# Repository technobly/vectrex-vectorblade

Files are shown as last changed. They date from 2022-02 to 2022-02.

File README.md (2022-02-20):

Vectrex Vectorblade PCB by Brett Walach
===

[Malban's Vectorblade PCB design](http://vide.malban.de/vectorblade/building-vectorblade/vectorblade-build-the-hardware), optimized with single gate SMT IC's (AND & NOT), 8 color RGB LED, and some gorgeous artwork applied.  Looks great in black soldermask with ENIG (gold flash) finish!

Yes these fit in [Sean Kelly reproduction cartridge shells](http://www.vectrexmulti.com/order2.html#!/Vectrex-Empty-Cartridge-Shells/c/38886086/offset=0&sort=normal) perfectly!

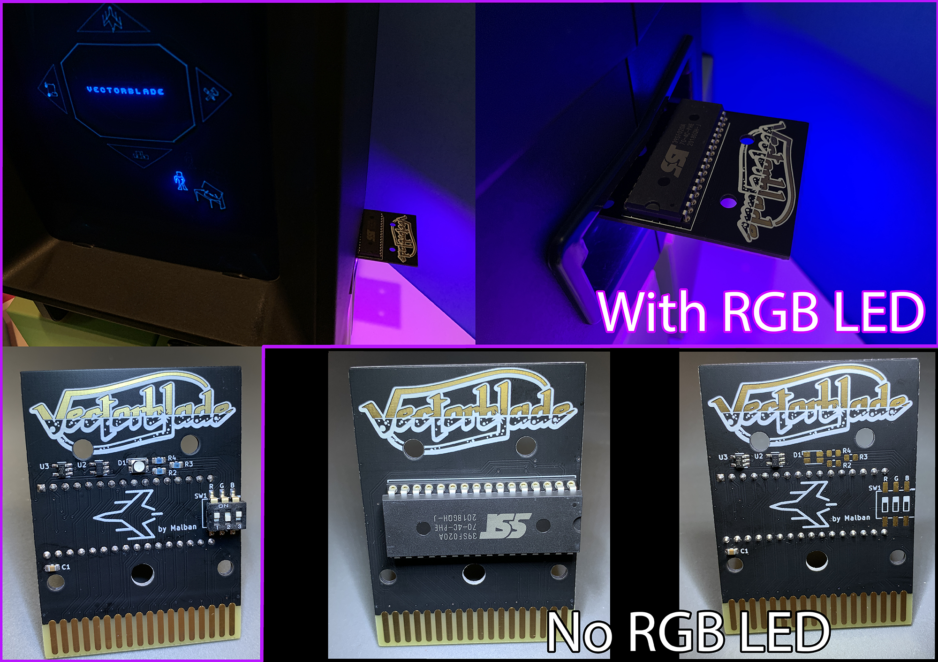
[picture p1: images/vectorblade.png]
VB


BOM and Parts ordering
===

All the parts are described in [Bill of Materials](bom/)

You can use this Digi-Key shared cart to order the parts!
[Vectrex Vectorblade](https://www.digikey.com/short/90np89zn)

Ordering PCB's
===

OSHPark is a good place to order with purple or the new "after dark" theme color scheme.  You can upload the KiCad `vextrex-vectorblade.kicad_pcb` there directly.  I would download this entire Github repo ZIP file first though instead of just trying to save the PCB file from your browser.

Another way to order PCB's is by using the included [gerbers](gerbers/vectrex-vectorblade-v1.0.zip) and uploading those with all of the necessary specs to companies like [PCBWay](https://www.pcbway.com) or [JLCPCB](https://jlcpcb.com)

Don't forget to make your board finish at least ENIG (gold flash) with a 45 degree chamfered edge.

LICENSE
===

CERN OHL v2.0 Permissive - essentially do whatever you want, but if you make a ton of money off of this... [buy me a coffee please!](https://buymeacoffee.com/walach)  Full [LICENSE here](LICENSE)

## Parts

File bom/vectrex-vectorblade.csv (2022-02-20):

Date: | Sunday, October 04, 2020 at 12:01:03 PM
Tool: | Eeschema (5.1.6-87-g1447494bc)
Generator: | /private/var/folders/z4/810dpjjx40sdk49yrs8fc2m80000gn/T/AppTranslocation/1DF89409-4AD7-4826-80D4-C05ED8546A72/d/kicad.app/Contents/SharedSupport/plugins/bom_csv_grouped_by_value_with_fp.py
Component Count: | 10
Ref | Qnty | Value | Cmp name | Footprint | Description | Vendor
C1, | 1 | 0.1uF 0805 | C | Capacitor_SMD:C_0805_2012Metric_Pad1.15x1.40mm_HandSolder | Unpolarized capacitor
D1, | 1 | ASMB-MTB0-0A3A2 | ASMB-MTB0-0A3A2 | vectrex-vectorblade:LED_Avago_PLCC4_3.2x2.8mm_CW | Tricolor Black Surface LED, Common Anode Pin 1, PLCC-4
R2, R3, | 2 | 150 0805 | R | Resistor_SMD:R_0805_2012Metric_Pad1.15x1.40mm_HandSolder | Resistor
R4, | 1 | 200 0805 | R | Resistor_SMD:R_0805_2012Metric_Pad1.15x1.40mm_HandSolder | Resistor
SW1, | 1 | SW_DIP_x03 | SW_DIP_x03 | Button_Switch_SMD:SW_DIP_SPSTx03_Slide_6.7x9.18mm_W8.61mm_P2.54mm_LowProfile | 3x DIP Switch, Single Pole Single Throw (SPST) switch, small symbol
U1, | 1 | SST39SF020 | SST39SF020 | Package_DIP:DIP-32_W15.24mm_Socket | Silicon Storage Technology (SSF) 256k x 8 Flash ROM
U1, | 1 | 115-87-632-41-003101 | 115-87-632-41-003101 | Package_DIP:DIP-32_W15.24mm_Socket | CONN IC DIP SOCKET 32POS GOLD
U2, | 1 | NC7ST08M5X (do not substitute) | NC7ST08M5X (do not substitute) | Package_TO_SOT_SMD:SOT-23-5_HandSoldering | Single AND Gate, Low-Voltage CMOS
U3, | 1 | SN74AHC1G04DBVR (Schmitt-Trigger) | 74AHC1G04 | Package_TO_SOT_SMD:SOT-23-5_HandSoldering | Single NOT Gate, Low-Voltage CMOS

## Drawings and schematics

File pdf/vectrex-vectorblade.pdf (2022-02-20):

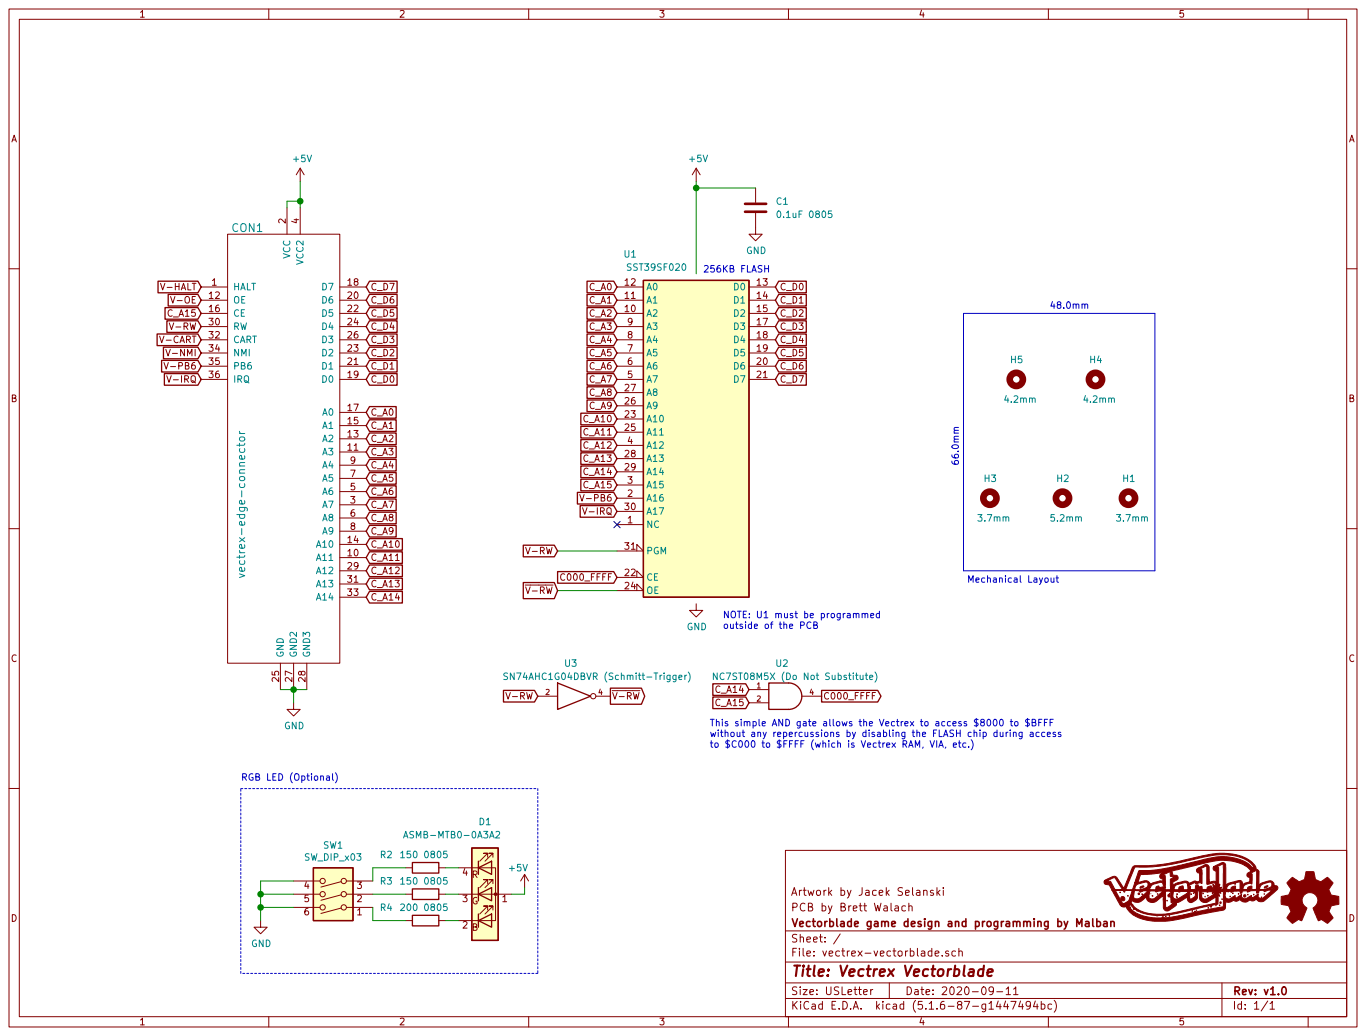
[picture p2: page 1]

4 A6 5 A8 6 A5 7 A9 8 A4 9 A11 10 D6 20 RW 30 A3 11 D1 21 A13 31 OE 12 D5 22 CART 32 A2 13 D2 23 A14 33 A10 14 D4 24 NMI 34 A1 15 GND 25 PB6 35 CE 16 D3 26

NOTE: U1 must be programmed outside of the PCB

This simple AND gate allows the Vectrex to access $8000 to $BFFF
without any repercussions by disabling the FLASH chip during access
to $C000 to $FFFF (which is Vectrex RAM, VIA, etc.)

Artwork by Jacek Selanski
PCB by Brett Walach
File: vectrex-vectorblade.sch Sheet: / Vectorblade game design and programming by Malban

Id: 1/1 Title: Vectrex Vectorblade

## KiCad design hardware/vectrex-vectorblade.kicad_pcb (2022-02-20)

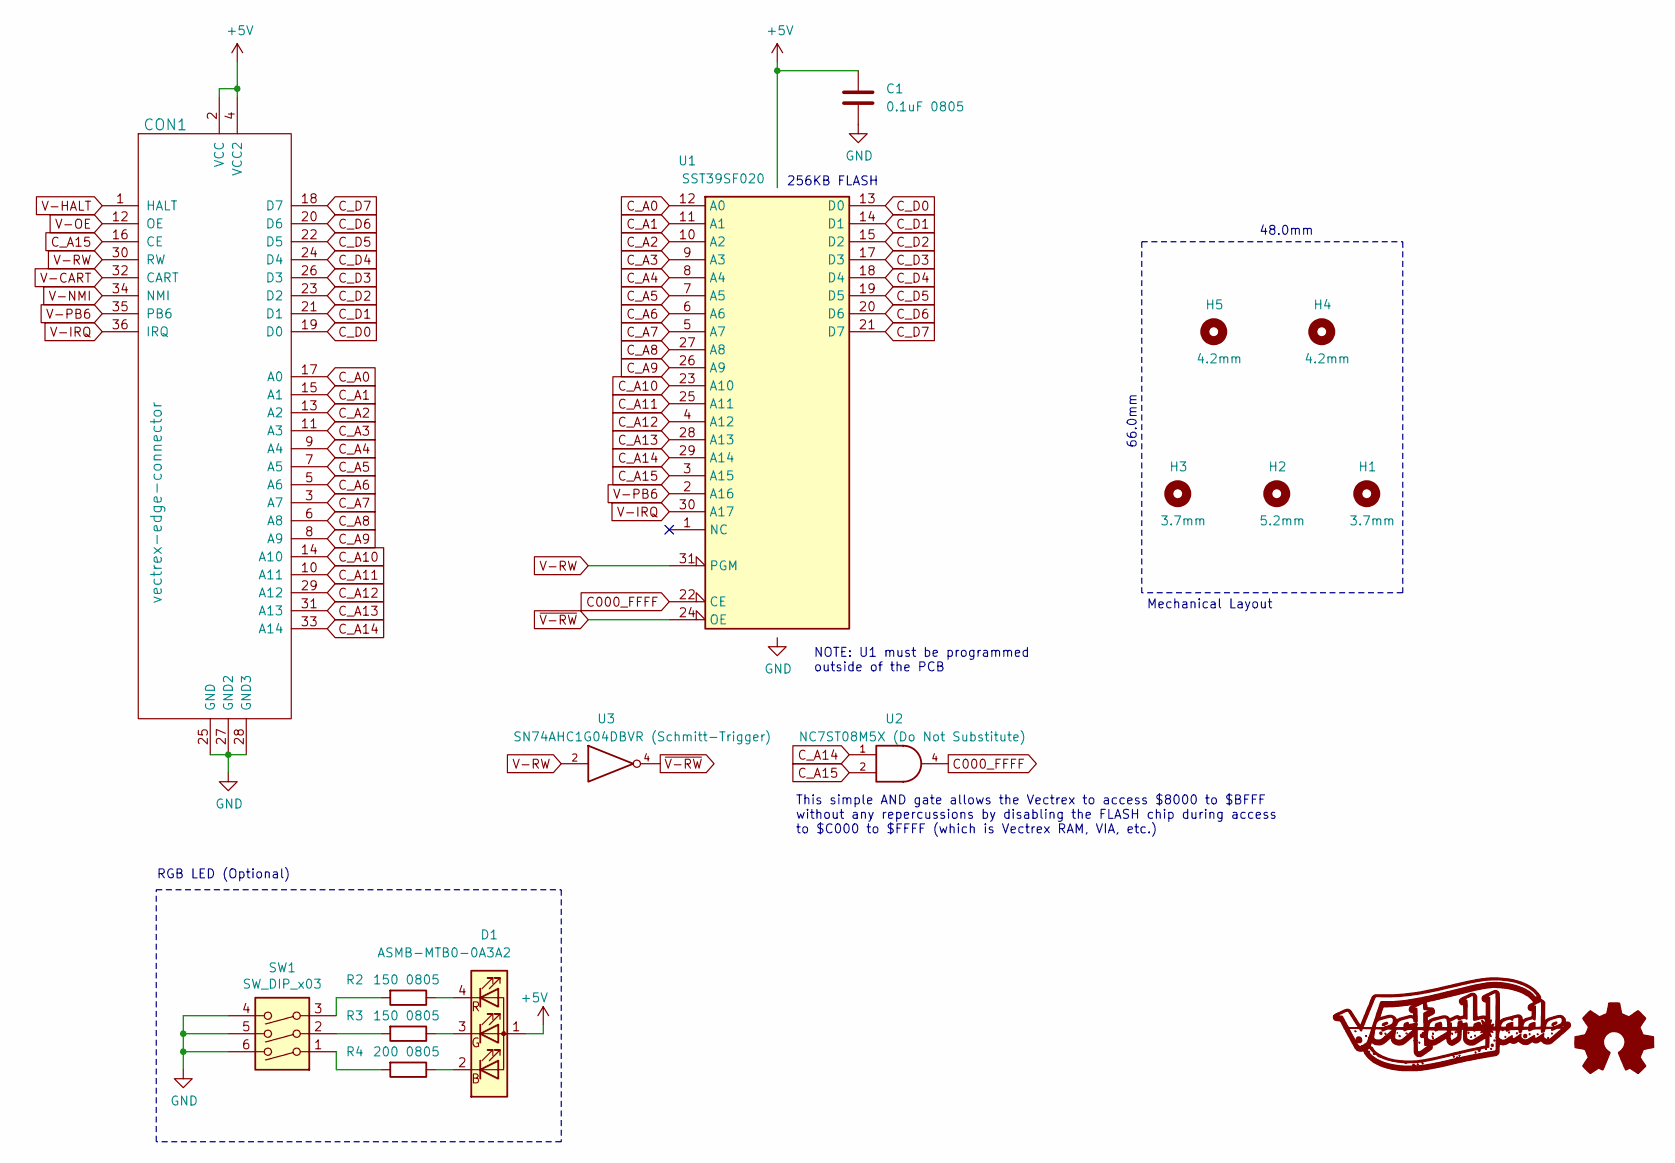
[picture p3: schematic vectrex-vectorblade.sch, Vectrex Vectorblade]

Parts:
C1: 0.1uF 0805; C_0805_2012Metric_Pad1.15x1.40mm_HandSolder
CON1: vectrex-edge-connector; vectrex-edge-connector-thinner-no-soldermask
D1: ASMB-MTB0-0A3A2; LED_Avago_PLCC4_3.2x2.8mm_CW
H1, H3: 3.7mm; Mounting_Hole_D3.7mm
H2: 5.2mm; Mounting_Hole_D5.2mm
H4, H5: 4.2mm; Mounting_Hole_D4.2mm
R2, R3: 150 0805; R_0805_2012Metric_Pad1.15x1.40mm_HandSolder
R4: 200 0805; R_0805_2012Metric_Pad1.15x1.40mm_HandSolder
SW1: SW_DIP_x03; SW_DIP_SPSTx03_Slide_6.7x9.18mm_W8.61mm_P2.54mm_LowProfile
U1: SST39SF020; DIP-32_W15.24mm_Socket
U2: NC7ST08M5X (Do Not Substitute); SOT-23-5_HandSoldering
U3: SN74AHC1G04DBVR (Schmitt-Trigger); SOT-23-5_HandSoldering

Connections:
+5V: C1.1, CON1.2 (VCC), CON1.4 (VCC2), D1.1 (A), U1.32 (VCC), U2.5 (VCC), U3.5 (VCC)
C000_FFFF: U1.22 (CE), U2.4
C_A0: CON1.17 (A0), U1.12 (A0)
C_A1: CON1.15 (A1), U1.11 (A1)
C_A2: CON1.13 (A2), U1.10 (A2)
C_A3: CON1.11 (A3), U1.9 (A3)
C_A4: CON1.9 (A4), U1.8 (A4)
C_A5: CON1.7 (A5), U1.7 (A5)
C_A6: CON1.5 (A6), U1.6 (A6)
C_A7: CON1.3 (A7), U1.5 (A7)
C_A8: CON1.6 (A8), U1.27 (A8)
C_A9: CON1.8 (A9), U1.26 (A9)
C_A10: CON1.14 (A10), U1.23 (A10)
C_A11: CON1.10 (A11), U1.25 (A11)
C_A12: CON1.29 (A12), U1.4 (A12)
C_A13: CON1.31 (A13), U1.28 (A13)
C_A14: CON1.33 (A14), U1.29 (A14), U2.1
C_A15: CON1.16 (CE), U1.3 (A15), U2.2
C_D0: CON1.19 (D0), U1.13 (D0)
C_D1: CON1.21 (D1), U1.14 (D1)
C_D2: CON1.23 (D2), U1.15 (D2)
C_D3: CON1.26 (D3), U1.17 (D3)
C_D4: CON1.24 (D4), U1.18 (D4)
C_D5: CON1.22 (D5), U1.19 (D5)
C_D6: CON1.20 (D6), U1.20 (D6)
C_D7: CON1.18 (D7), U1.21 (D7)
GND: C1.2, CON1.25 (GND), CON1.27 (GND2), CON1.28 (GND3), SW1.4, SW1.5, SW1.6, U1.16 (GND), U2.3 (GND), U3.3 (GND)
unnamed: D1.2 (BK), R4.1
unnamed: D1.3 (GK), R3.1
unnamed: D1.4 (RK), R2.1
unnamed: R2.2, SW1.3
unnamed: R3.2, SW1.2
unnamed: R4.2, SW1.1
V-CART: CON1.32 (CART)
V-HALT: CON1.1 (HALT)
V-IRQ: CON1.36 (IRQ), U1.30 (A17)
V-NMI: CON1.34 (NMI)
V-OE: CON1.12 (OE)
V-PB6: CON1.35 (PB6), U1.2 (A16)
V-RW: CON1.30 (RW), U1.31 (PGM), U3.2
~V-RW: U1.24 (OE), U3.4

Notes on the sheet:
256KB FLASH
NOTE: U1 must be programmed outside of the PCB
RGB LED (Optional)
48.0mm
66.0mm
This simple AND gate allows the Vectrex to access $8000 to $BFFF without any repercussions by disabling the FLASH chip during access to $C000 to $FFFF (which is Vectrex RAM, VIA, etc.)
Mechanical Layout

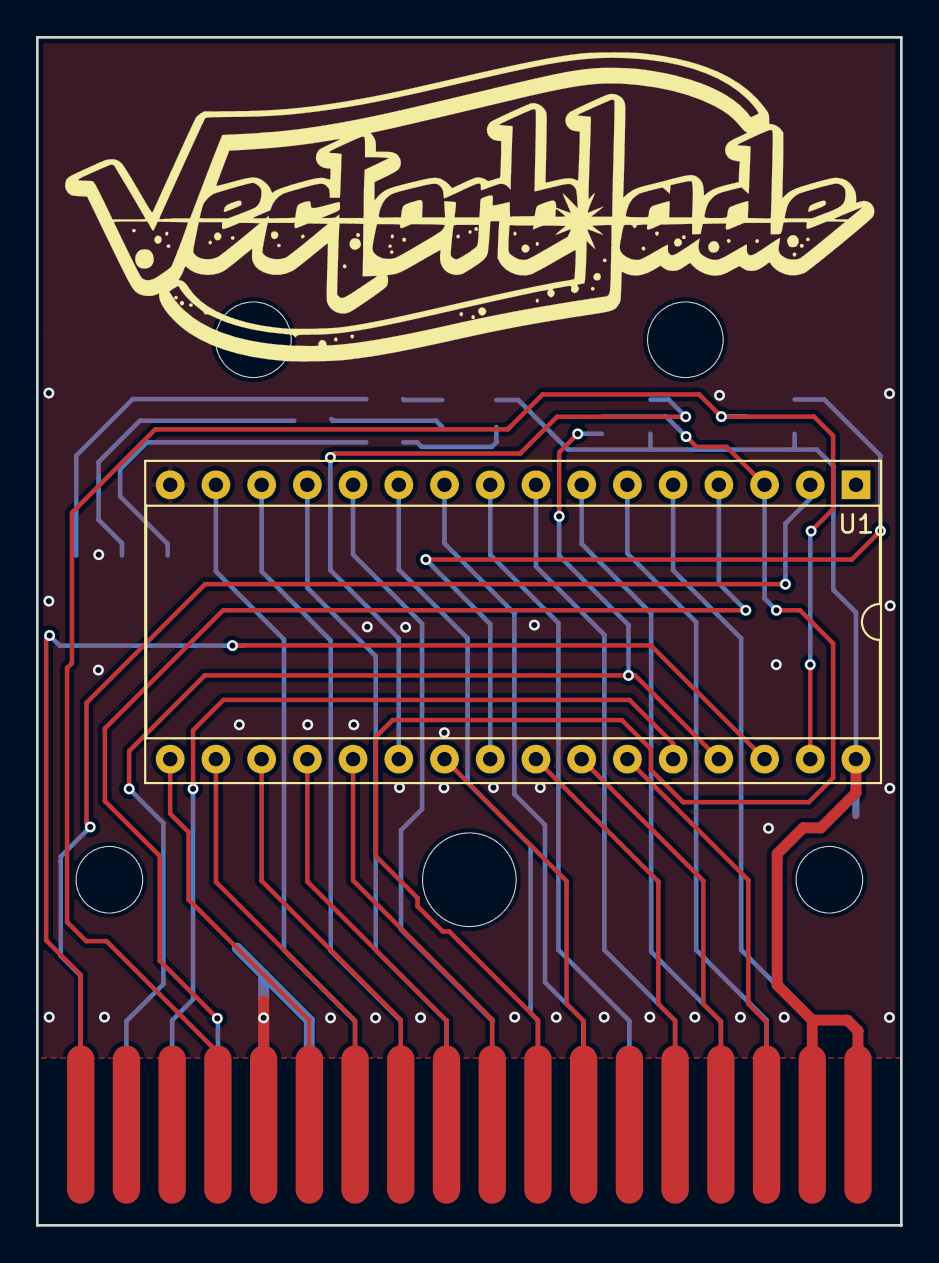
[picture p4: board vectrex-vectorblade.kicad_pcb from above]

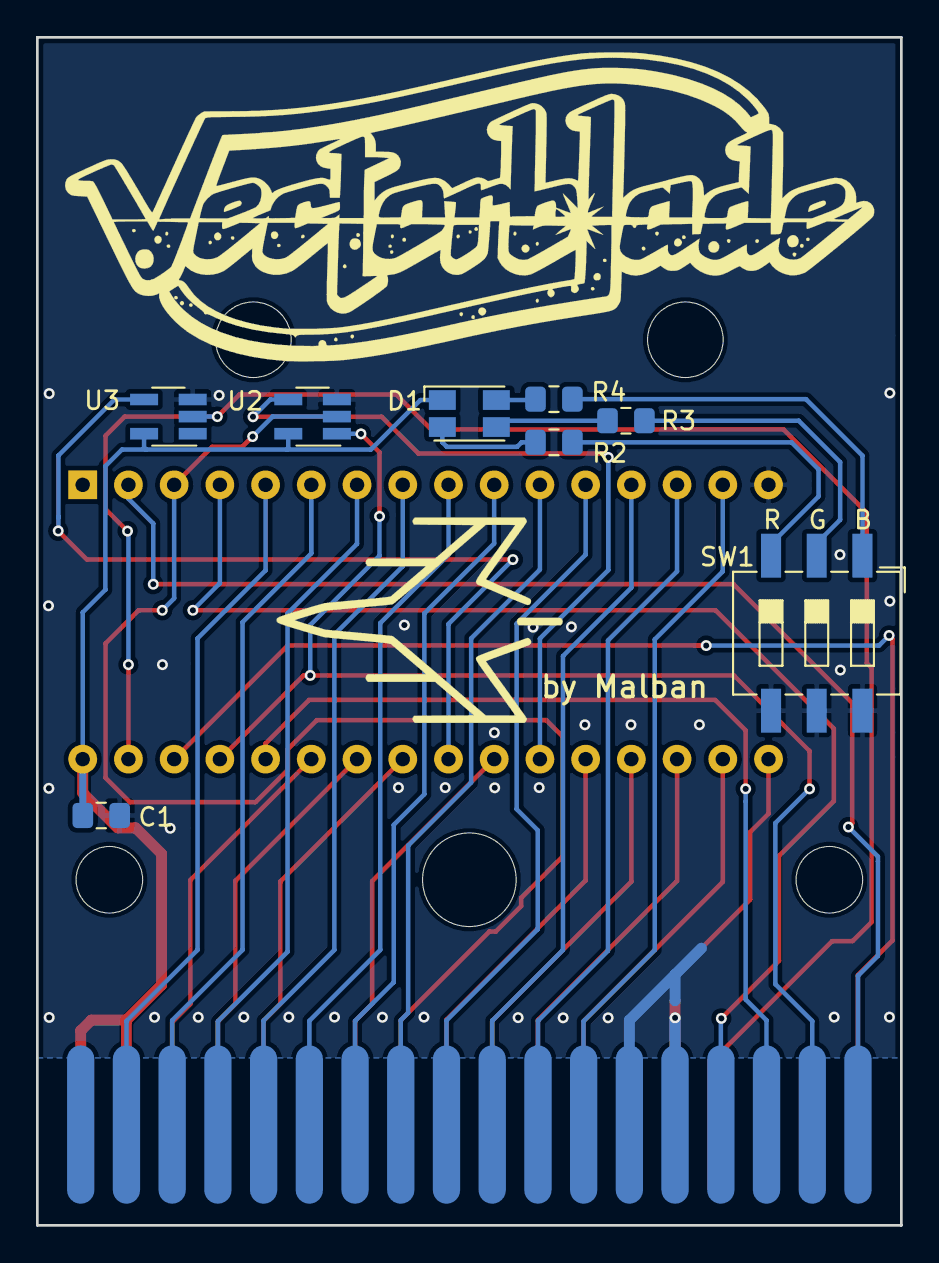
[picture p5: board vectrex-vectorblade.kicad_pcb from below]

Board: 2 copper layers, 48.0 x 66.0 mm, 15 parts (8 on the bottom side), 37 nets.
